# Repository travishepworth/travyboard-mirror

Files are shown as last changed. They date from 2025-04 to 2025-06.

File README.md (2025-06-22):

<h1 align="center">
travyboard
</h1>

## A corne style keyboard with the Pico SDK and TinyUSB

A personal project demonstrating how to build a keyboard using the
Raspberry Pi Pico microcontroller in c++. Intent on expanding to create more powerful
keyboards with more features (wireless coming soon).

### Photos
<div style="display: flex; justify-content: space-around;">
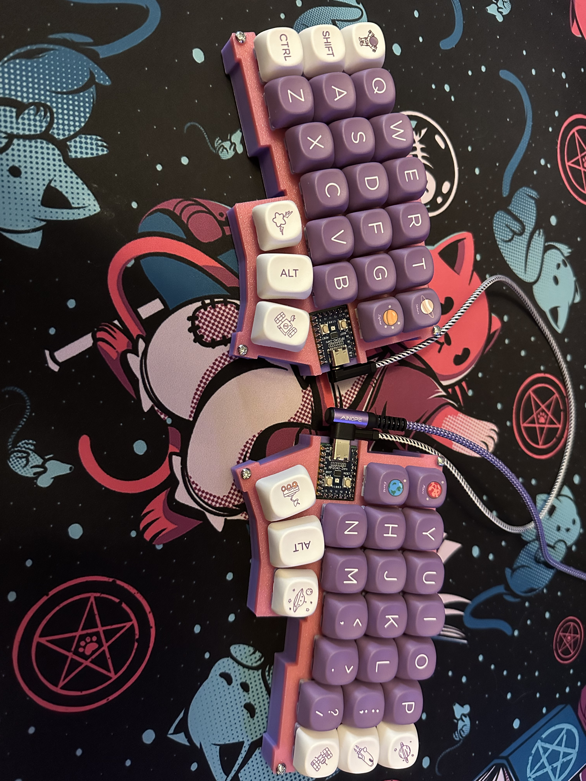
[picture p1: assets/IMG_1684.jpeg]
First Photo
  
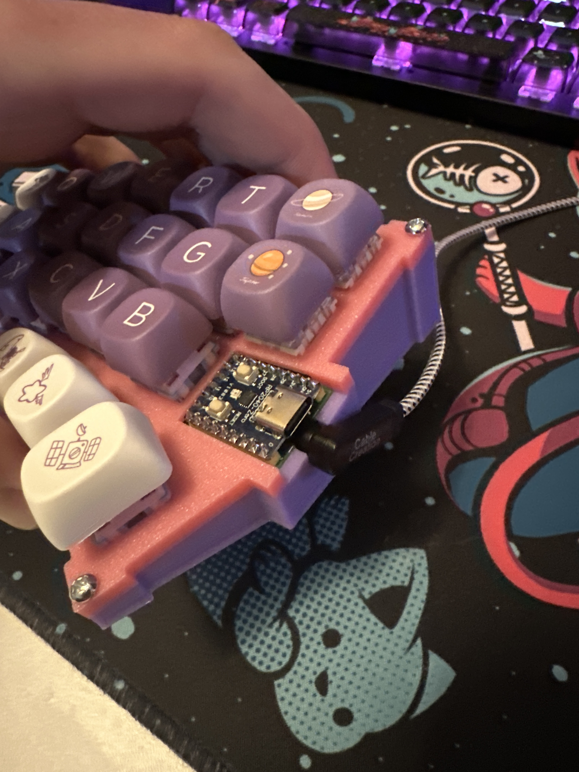
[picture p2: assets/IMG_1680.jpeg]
Second Photo
  
</div>

### Features

- 3d printed case
- 3x6 matrix with 3 button thumb clusters and 2 mode keys
- Split one way communication
- Full keymap controlled by the master pico
- Dynamic layers
- ws2812 rgb leds on every key

### Requirements for building

- Two Raspberry Pi Picos. I have the waveshare zeroes on the actual PCB.
- Cmake and gcc/g++ installed. May want to set up wsl2 on Windows.

### Setup

1. Clone this repository:

```sh
git clone https://github.com/travmonkey/travyboard.git
cd travyboard
```

2. Update the submodules:

```sh
# Includes the pico-sdk and rf modules
git submodule update --init --recursive
```

3. To build the project you need gcc-arm-none-eabi, cmake, and make installed:

```sh
cd firmware
mkdir build && cd build
cmake -DCMAKE_EXPORT_COMPILE_COMMANDS=ON ..
make
```

5. Mount and flash both picos with the master and slave compiled .uf2 code.
```sh
mkdir ~/rpi-pico
sudo fdisk -l # Find the pico device
sudo mount /dev/sdx1 /home/`<user>`/rpi-pico
sudo cp src/devices/right_half/right_half.uf2 /home/`<user>`/rpi-pico/
sudo cp src/devices/left_half/left_half.uf2 /home/`<user>`/rpi-pico/
```

Alternativly you can modify the script I wrote to include your own directories and username

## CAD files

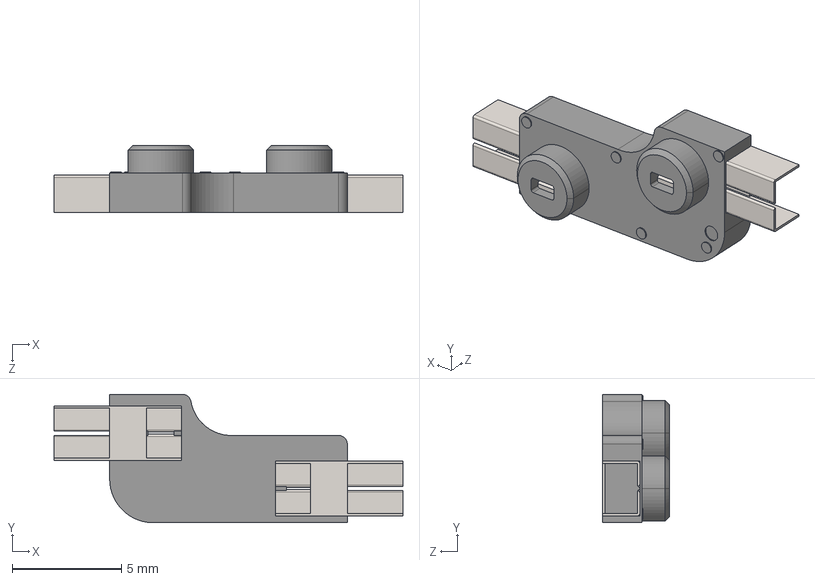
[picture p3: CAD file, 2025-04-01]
pcb/models/Kailh Hotswap MX.step
16.0 x 5.89 x 3.05 mm
Kailh Hotswap MX
Kailh Hotswap MX Inlay
Kailh Hotswap MX Inlay 2

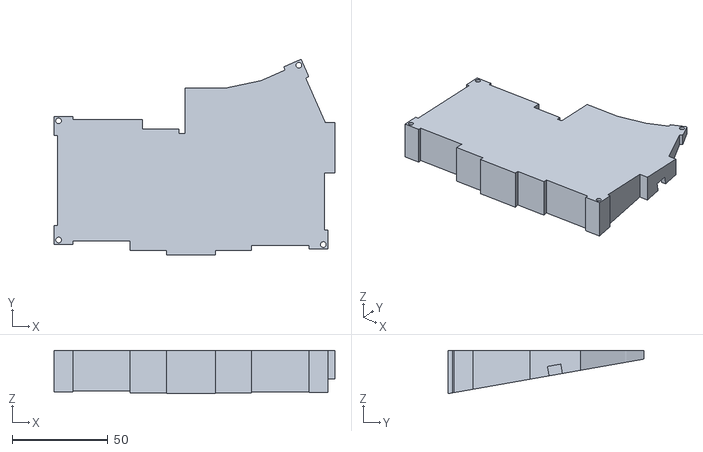
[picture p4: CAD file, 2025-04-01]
stls/Bottom.stl
147.1 x 102.4 x 22.7

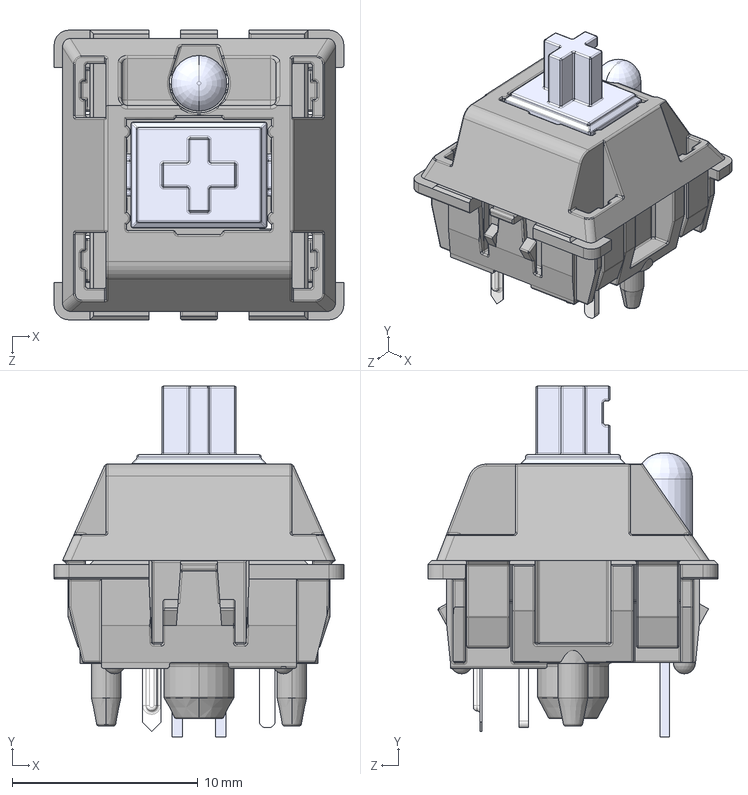
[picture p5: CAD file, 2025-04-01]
pcb/models/MX .STEP
15.6 x 18.9 x 15.6 mm
MX 轴 按键′_ü___¨1
MX 轴 轴体áì_¨￠¨__
MX粣 拸簽LEDLEDLED
MX轴 轴体 底部 μ×2__默认_á2____è_
针脚___默认__è_

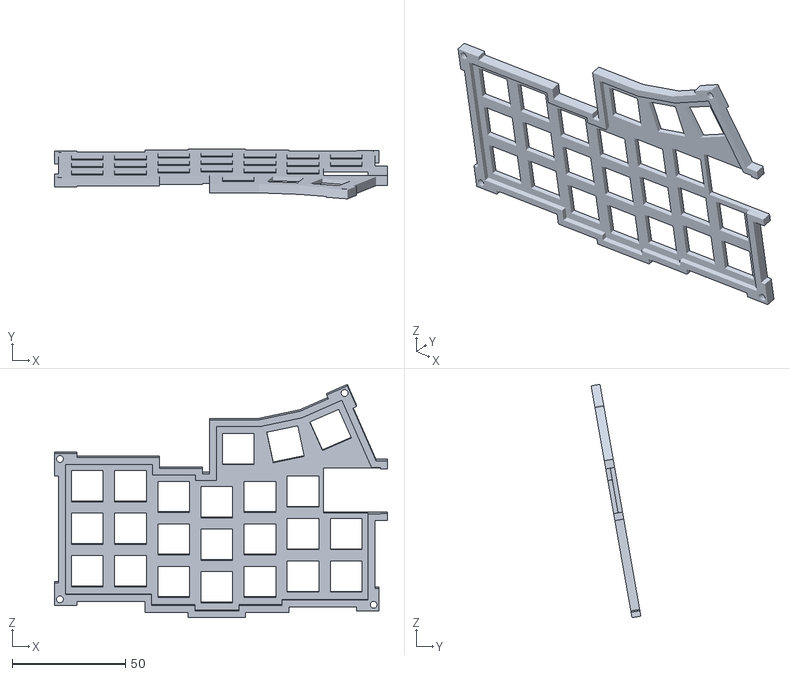
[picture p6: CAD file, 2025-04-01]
stls/Case - Top.stl
147.1 x 22.0 x 103.1

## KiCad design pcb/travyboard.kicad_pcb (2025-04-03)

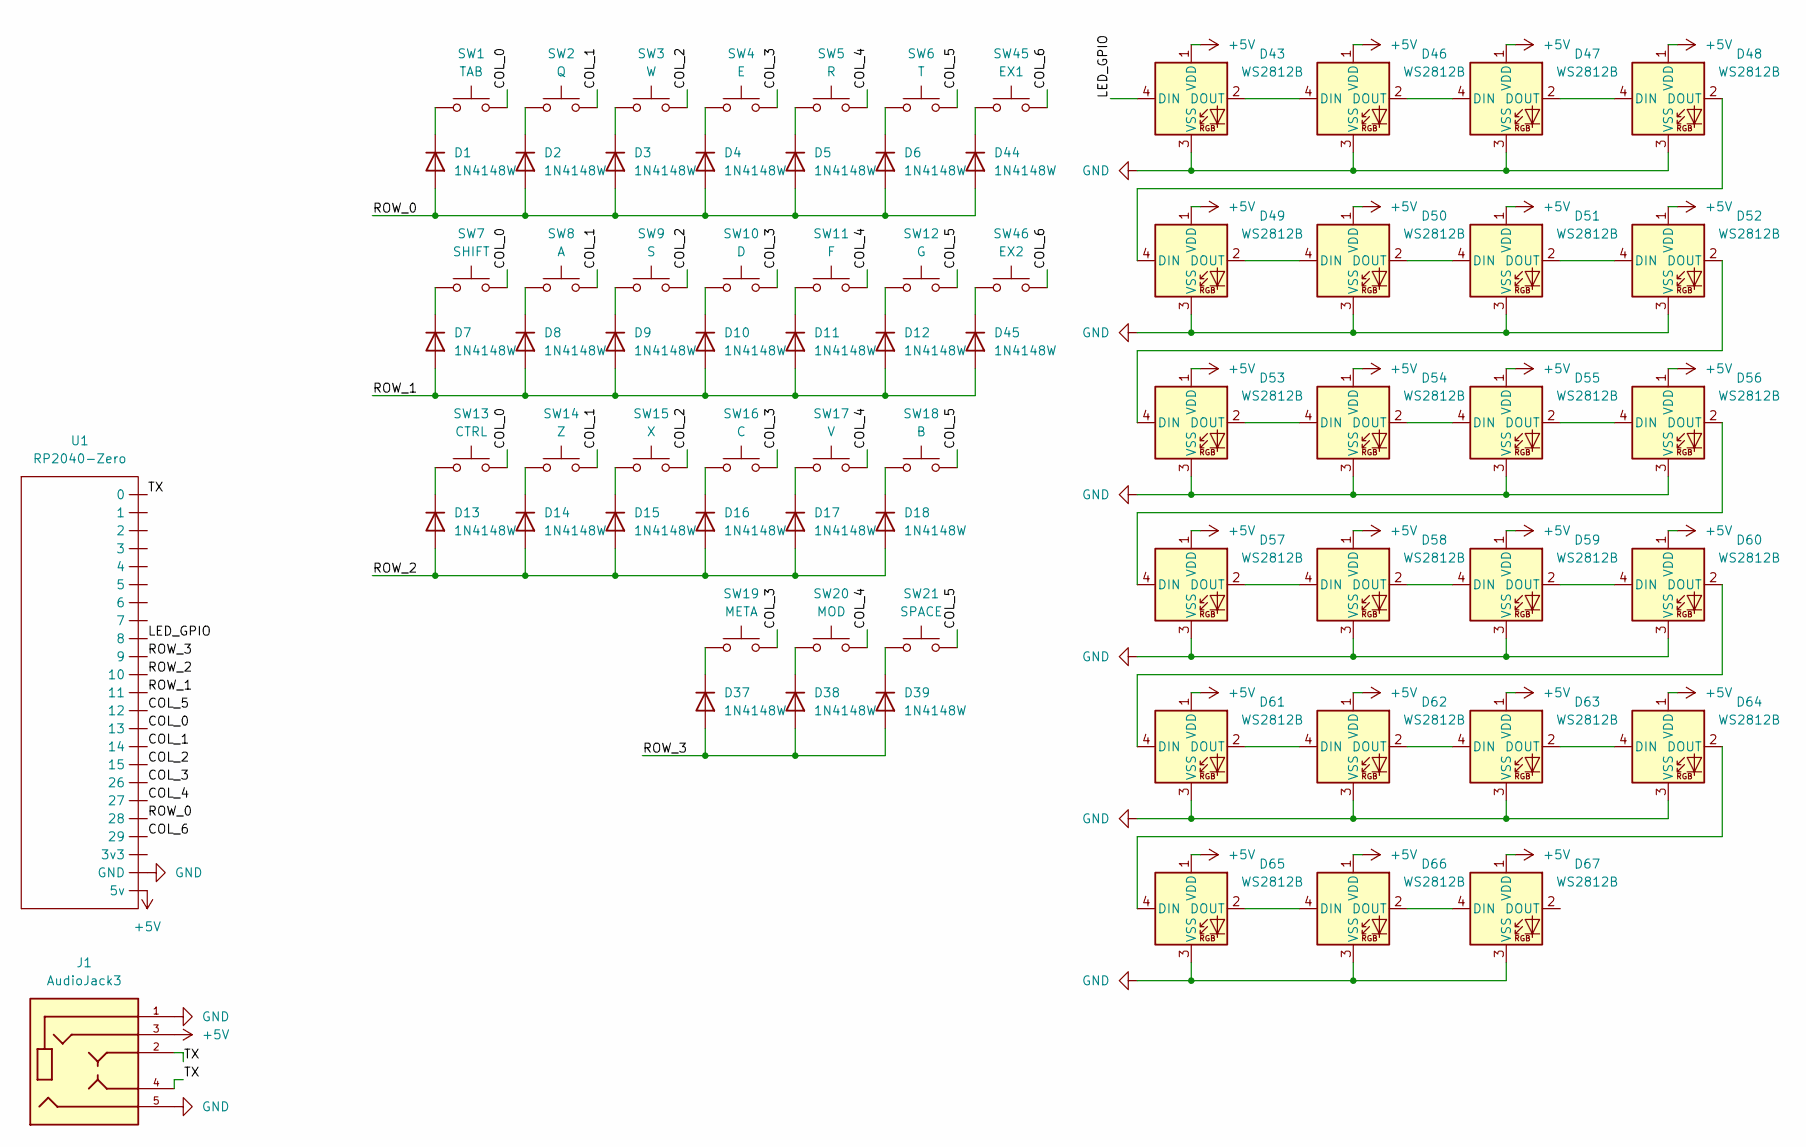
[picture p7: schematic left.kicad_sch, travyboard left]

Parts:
D1, D2, D3, D4, D5, D6, D7, D8, D9, D10, D11, D12, D13, D14, D15, D16, D17, D18, D37, D38, D39, D44, D45: 1N4148W; D_SOD-123
D43, D46, D47, D48, D49, D50, D51, D52, D53, D54, D55, D56, D57, D58, D59, D60, D61, D62, D63, D64, D65, D66, D67: WS2812B; LED_WS2812B_PLCC4_5.0x5.0mm_P3.2mm
J1: AudioJack3; CUI_SJ-3501-SMT-TR; PARTREV 1.05
SW1: TAB; CherryMX_Hotswap
SW2: Q; CherryMX_Hotswap
SW3: W; CherryMX_Hotswap
SW4: E; CherryMX_Hotswap
SW5: R; CherryMX_Hotswap
SW6: T; CherryMX_Hotswap
SW7: SHIFT; CherryMX_Hotswap
SW8: A; CherryMX_Hotswap
SW9: S; CherryMX_Hotswap
SW10: D; CherryMX_Hotswap
SW11: F; CherryMX_Hotswap
SW12: G; CherryMX_Hotswap
SW13: CTRL; CherryMX_Hotswap
SW14: Z; CherryMX_Hotswap
SW15: X; CherryMX_Hotswap
SW16: C; CherryMX_Hotswap
SW17: V; CherryMX_Hotswap
SW18: B; CherryMX_Hotswap
SW19: META; CherryMX_Hotswap
SW20: MOD; CherryMX_Hotswap
SW21: SPACE; CherryMX_Hotswap
SW45: EX1; CherryMX_Hotswap
SW46: EX2; CherryMX_Hotswap
U1: RP2040-Zero

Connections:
+5V: D43.1 (VDD), D46.1 (VDD), D47.1 (VDD), D48.1 (VDD), D49.1 (VDD), D50.1 (VDD), D51.1 (VDD), D52.1 (VDD), D53.1 (VDD), D54.1 (VDD), D55.1 (VDD), D56.1 (VDD), D57.1 (VDD), D58.1 (VDD), D59.1 (VDD), D60.1 (VDD), D61.1 (VDD), D62.1 (VDD), D63.1 (VDD), D64.1 (VDD), D65.1 (VDD), D66.1 (VDD), D67.1 (VDD), J1.3, U1.5v; also elsewhere on the board
/Left Half/COL_0: SW1.2, SW7.2, SW13.2, U1.13
/Left Half/COL_1: SW2.2, SW8.2, SW14.2, U1.14
/Left Half/COL_2: SW3.2, SW9.2, SW15.2, U1.15
/Left Half/COL_3: SW4.2, SW10.2, SW16.2, SW19.2, U1.26
/Left Half/COL_4: SW5.2, SW11.2, SW17.2, SW20.2, U1.27
/Left Half/COL_5: SW6.2, SW12.2, SW18.2, SW21.2, U1.12
/Left Half/COL_6: SW45.2, SW46.2, U1.29
/Left Half/LED_GPIO: D43.4 (DIN), U1.8
/Left Half/ROW_0: D1.2 (A), D2.2 (A), D3.2 (A), D4.2 (A), D5.2 (A), D6.2 (A), D44.2 (A), U1.28
/Left Half/ROW_1: D7.2 (A), D8.2 (A), D9.2 (A), D10.2 (A), D11.2 (A), D12.2 (A), D45.2 (A), U1.11
/Left Half/ROW_2: D13.2 (A), D14.2 (A), D15.2 (A), D16.2 (A), D17.2 (A), D18.2 (A), U1.10
/Left Half/ROW_3: D37.2 (A), D38.2 (A), D39.2 (A), U1.9
/Left Half/TX: J1.2, J1.4, U1.0
GND: D43.3 (VSS), D46.3 (VSS), D47.3 (VSS), D48.3 (VSS), D49.3 (VSS), D50.3 (VSS), D51.3 (VSS), D52.3 (VSS), D53.3 (VSS), D54.3 (VSS), D55.3 (VSS), D56.3 (VSS), D57.3 (VSS), D58.3 (VSS), D59.3 (VSS), D60.3 (VSS), D61.3 (VSS), D62.3 (VSS), D63.3 (VSS), D64.3 (VSS), D65.3 (VSS), D66.3 (VSS), D67.3 (VSS), J1.1, J1.5, U1.GND; also elsewhere on the board
unnamed: D1.1 (K), SW1.1
unnamed: D2.1 (K), SW2.1
unnamed: D3.1 (K), SW3.1
unnamed: D4.1 (K), SW4.1
unnamed: D5.1 (K), SW5.1
unnamed: D6.1 (K), SW6.1
unnamed: D7.1 (K), SW7.1
unnamed: D8.1 (K), SW8.1
unnamed: D9.1 (K), SW9.1
unnamed: D10.1 (K), SW10.1
unnamed: D11.1 (K), SW11.1
unnamed: D12.1 (K), SW12.1
unnamed: D13.1 (K), SW13.1
unnamed: D14.1 (K), SW14.1
unnamed: D15.1 (K), SW15.1
unnamed: D16.1 (K), SW16.1
unnamed: D17.1 (K), SW17.1
unnamed: D18.1 (K), SW18.1
unnamed: D37.1 (K), SW19.1
unnamed: D38.1 (K), SW20.1
unnamed: D39.1 (K), SW21.1
unnamed: D43.2 (DOUT), D46.4 (DIN)
unnamed: D44.1 (K), SW45.1
unnamed: D45.1 (K), SW46.1
unnamed: D46.2 (DOUT), D47.4 (DIN)
unnamed: D47.2 (DOUT), D48.4 (DIN)
unnamed: D48.2 (DOUT), D49.4 (DIN)
unnamed: D49.2 (DOUT), D50.4 (DIN)
unnamed: D50.2 (DOUT), D51.4 (DIN)
unnamed: D51.2 (DOUT), D52.4 (DIN)
unnamed: D52.2 (DOUT), D53.4 (DIN)
unnamed: D53.2 (DOUT), D54.4 (DIN)
unnamed: D54.2 (DOUT), D55.4 (DIN)
unnamed: D55.2 (DOUT), D56.4 (DIN)
unnamed: D56.2 (DOUT), D57.4 (DIN)
unnamed: D57.2 (DOUT), D58.4 (DIN)
unnamed: D58.2 (DOUT), D59.4 (DIN)
unnamed: D59.2 (DOUT), D60.4 (DIN)
unnamed: D60.2 (DOUT), D61.4 (DIN)
unnamed: D61.2 (DOUT), D62.4 (DIN)
unnamed: D62.2 (DOUT), D63.4 (DIN)
unnamed: D63.2 (DOUT), D64.4 (DIN)
unnamed: D64.2 (DOUT), D65.4 (DIN)
unnamed: D65.2 (DOUT), D66.4 (DIN)
unnamed: D66.2 (DOUT), D67.4 (DIN)

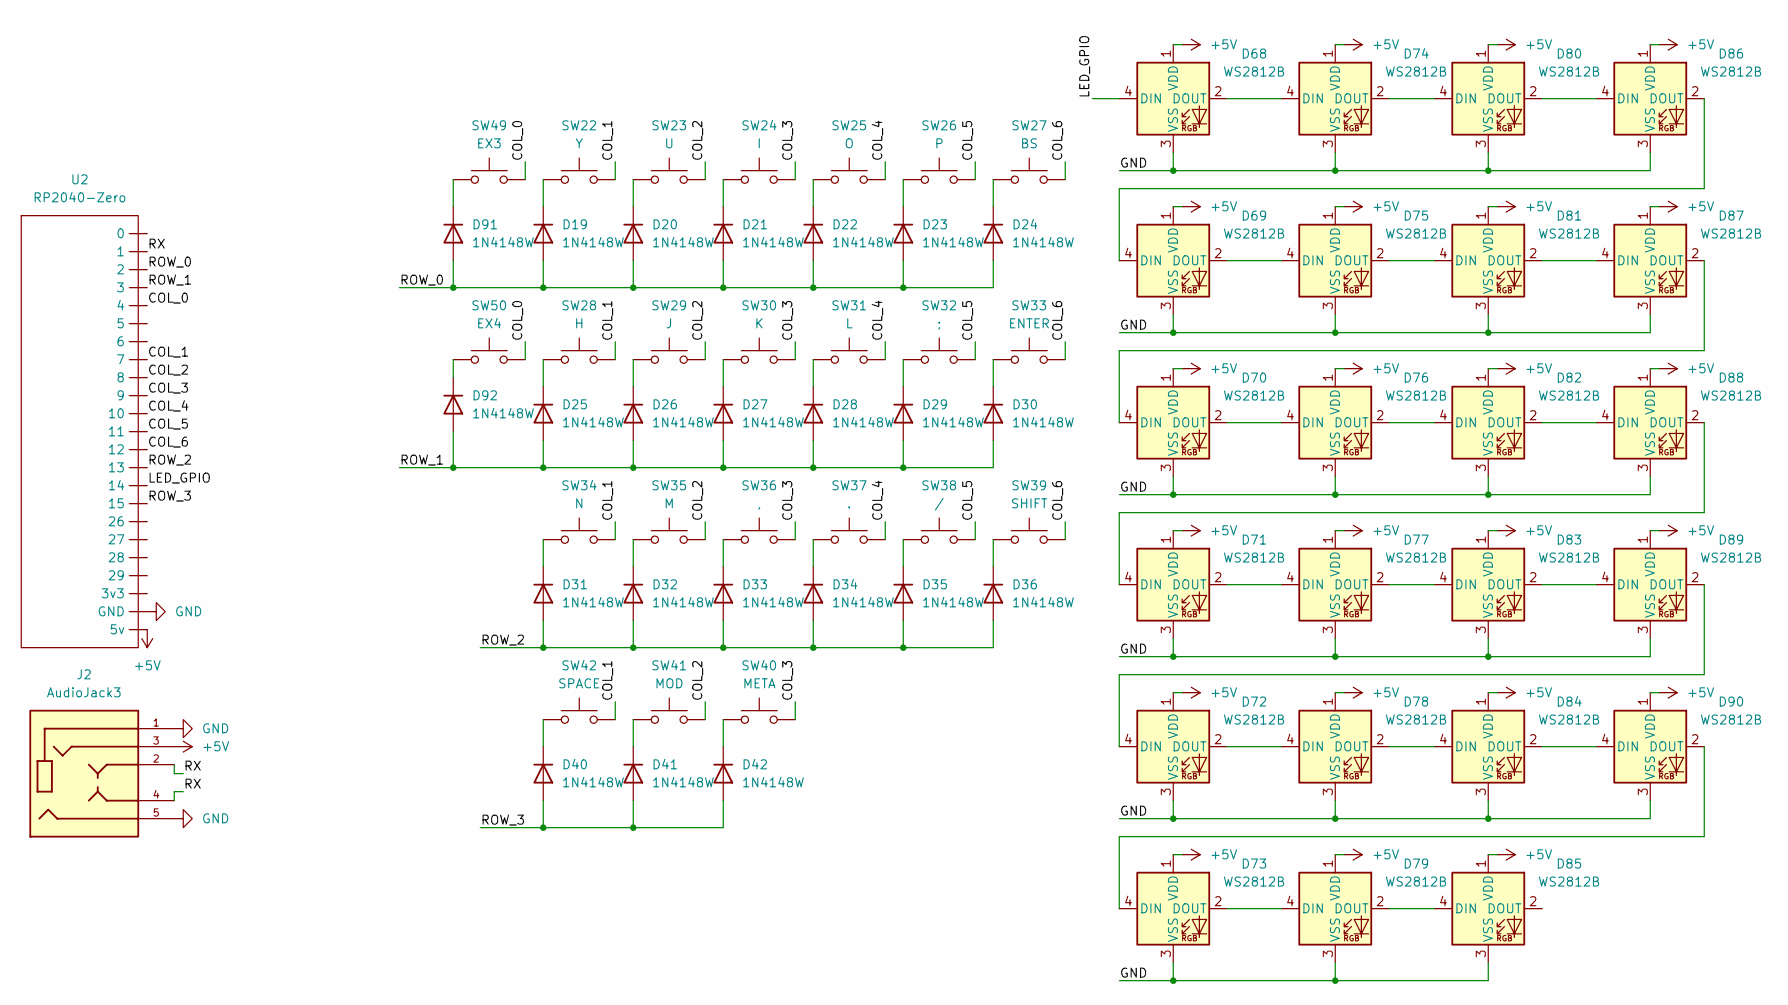
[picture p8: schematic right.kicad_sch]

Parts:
D19, D20, D21, D22, D23, D24, D25, D26, D27, D28, D29, D30, D31, D32, D33, D34, D35, D36, D40, D41, D42, D91, D92: 1N4148W; D_SOD-123
D68, D69, D70, D71, D72, D73, D74, D75, D76, D77, D78, D79, D80, D81, D82, D83, D84, D85, D86, D87, D88, D89, D90: WS2812B; LED_WS2812B_PLCC4_5.0x5.0mm_P3.2mm
J2: AudioJack3; CUI_SJ-3501-SMT-TR; PARTREV 1.05
SW22: Y; CherryMX_Hotswap
SW23: U; CherryMX_Hotswap
SW24: I; CherryMX_Hotswap
SW25: O; CherryMX_Hotswap
SW26: P; CherryMX_Hotswap
SW27: BS; CherryMX_Hotswap
SW28: H; CherryMX_Hotswap
SW29: J; CherryMX_Hotswap
SW30: K; CherryMX_Hotswap
SW31: L; CherryMX_Hotswap
SW32: ;; CherryMX_Hotswap
SW33: ENTER; CherryMX_Hotswap
SW34: N; CherryMX_Hotswap
SW35: M; CherryMX_Hotswap
SW36: ,; CherryMX_Hotswap
SW37: .; CherryMX_Hotswap
SW38: /; CherryMX_Hotswap
SW39: SHIFT; CherryMX_Hotswap
SW40: META; CherryMX_Hotswap
SW41: MOD; CherryMX_Hotswap
SW42: SPACE; CherryMX_Hotswap
SW49: EX3; CherryMX_Hotswap
SW50: EX4; CherryMX_Hotswap
U2: RP2040-Zero

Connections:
+5V: D68.1 (VDD), D69.1 (VDD), D70.1 (VDD), D71.1 (VDD), D72.1 (VDD), D73.1 (VDD), D74.1 (VDD), D75.1 (VDD), D76.1 (VDD), D77.1 (VDD), D78.1 (VDD), D79.1 (VDD), D80.1 (VDD), D81.1 (VDD), D82.1 (VDD), D83.1 (VDD), D84.1 (VDD), D85.1 (VDD), D86.1 (VDD), D87.1 (VDD), D88.1 (VDD), D89.1 (VDD), D90.1 (VDD), J2.3, U2.5v; also elsewhere on the board
/Right Half/COL_0: SW49.2, SW50.2, U2.4
/Right Half/COL_1: SW22.2, SW28.2, SW34.2, SW42.2, U2.7
/Right Half/COL_2: SW23.2, SW29.2, SW35.2, SW41.2, U2.8
/Right Half/COL_3: SW24.2, SW30.2, SW36.2, SW40.2, U2.9
/Right Half/COL_4: SW25.2, SW31.2, SW37.2, U2.10
/Right Half/COL_5: SW26.2, SW32.2, SW38.2, U2.11
/Right Half/COL_6: SW27.2, SW33.2, SW39.2, U2.12
/Right Half/LED_GPIO: D68.4 (DIN), U2.14
/Right Half/ROW_0: D19.2 (A), D20.2 (A), D21.2 (A), D22.2 (A), D23.2 (A), D24.2 (A), D91.2 (A), U2.2
/Right Half/ROW_1: D25.2 (A), D26.2 (A), D27.2 (A), D28.2 (A), D29.2 (A), D30.2 (A), D92.2 (A), U2.3
/Right Half/ROW_2: D31.2 (A), D32.2 (A), D33.2 (A), D34.2 (A), D35.2 (A), D36.2 (A), U2.13
/Right Half/ROW_3: D40.2 (A), D41.2 (A), D42.2 (A), U2.15
/Right Half/RX: J2.2, J2.4, U2.1
GND: D68.3 (VSS), D69.3 (VSS), D70.3 (VSS), D71.3 (VSS), D72.3 (VSS), D73.3 (VSS), D74.3 (VSS), D75.3 (VSS), D76.3 (VSS), D77.3 (VSS), D78.3 (VSS), D79.3 (VSS), D80.3 (VSS), D81.3 (VSS), D82.3 (VSS), D83.3 (VSS), D84.3 (VSS), D85.3 (VSS), D86.3 (VSS), D87.3 (VSS), D88.3 (VSS), D89.3 (VSS), D90.3 (VSS), J2.1, J2.5, U2.GND; also elsewhere on the board
unnamed: D19.1 (K), SW22.1
unnamed: D20.1 (K), SW23.1
unnamed: D21.1 (K), SW24.1
unnamed: D22.1 (K), SW25.1
unnamed: D23.1 (K), SW26.1
unnamed: D24.1 (K), SW27.1
unnamed: D25.1 (K), SW28.1
unnamed: D26.1 (K), SW29.1
unnamed: D27.1 (K), SW30.1
unnamed: D28.1 (K), SW31.1
unnamed: D29.1 (K), SW32.1
unnamed: D30.1 (K), SW33.1
unnamed: D31.1 (K), SW34.1
unnamed: D32.1 (K), SW35.1
unnamed: D33.1 (K), SW36.1
unnamed: D34.1 (K), SW37.1
unnamed: D35.1 (K), SW38.1
unnamed: D36.1 (K), SW39.1
unnamed: D40.1 (K), SW42.1
unnamed: D41.1 (K), SW41.1
unnamed: D42.1 (K), SW40.1
unnamed: D68.2 (DOUT), D74.4 (DIN)
unnamed: D69.4 (DIN), D86.2 (DOUT)
unnamed: D69.2 (DOUT), D75.4 (DIN)
unnamed: D70.4 (DIN), D87.2 (DOUT)
unnamed: D70.2 (DOUT), D76.4 (DIN)
unnamed: D71.4 (DIN), D88.2 (DOUT)
unnamed: D71.2 (DOUT), D77.4 (DIN)
unnamed: D72.4 (DIN), D89.2 (DOUT)
unnamed: D72.2 (DOUT), D78.4 (DIN)
unnamed: D73.4 (DIN), D90.2 (DOUT)
unnamed: D73.2 (DOUT), D79.4 (DIN)
unnamed: D74.2 (DOUT), D80.4 (DIN)
unnamed: D75.2 (DOUT), D81.4 (DIN)
unnamed: D76.2 (DOUT), D82.4 (DIN)
unnamed: D77.2 (DOUT), D83.4 (DIN)
unnamed: D78.2 (DOUT), D84.4 (DIN)
unnamed: D79.2 (DOUT), D85.4 (DIN)
unnamed: D80.2 (DOUT), D86.4 (DIN)
unnamed: D81.2 (DOUT), D87.4 (DIN)
unnamed: D82.2 (DOUT), D88.4 (DIN)
unnamed: D83.2 (DOUT), D89.4 (DIN)
unnamed: D84.2 (DOUT), D90.4 (DIN)
unnamed: D91.1 (K), SW49.1
unnamed: D92.1 (K), SW50.1

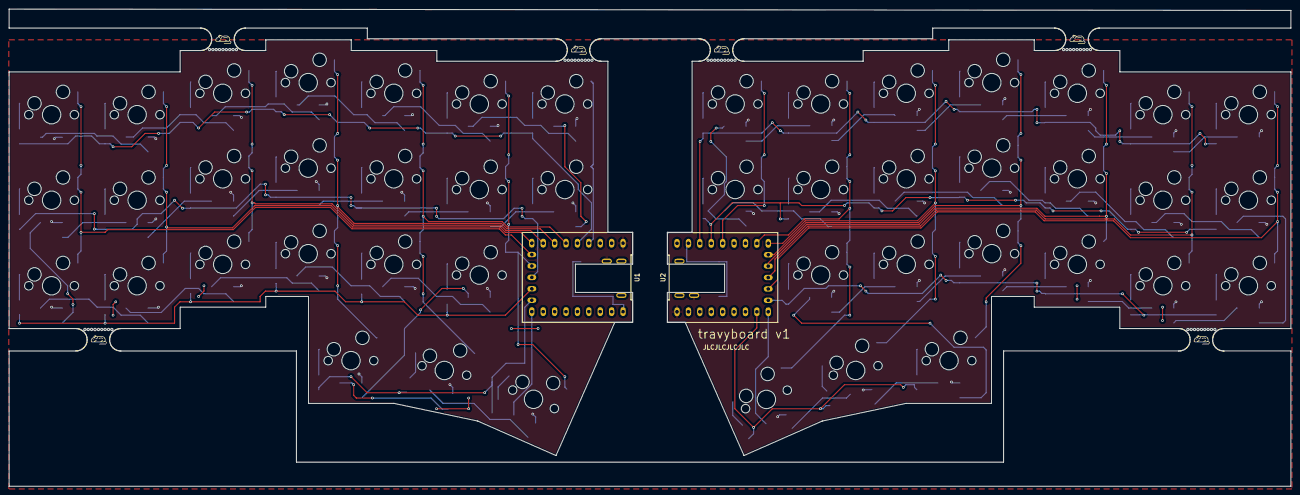
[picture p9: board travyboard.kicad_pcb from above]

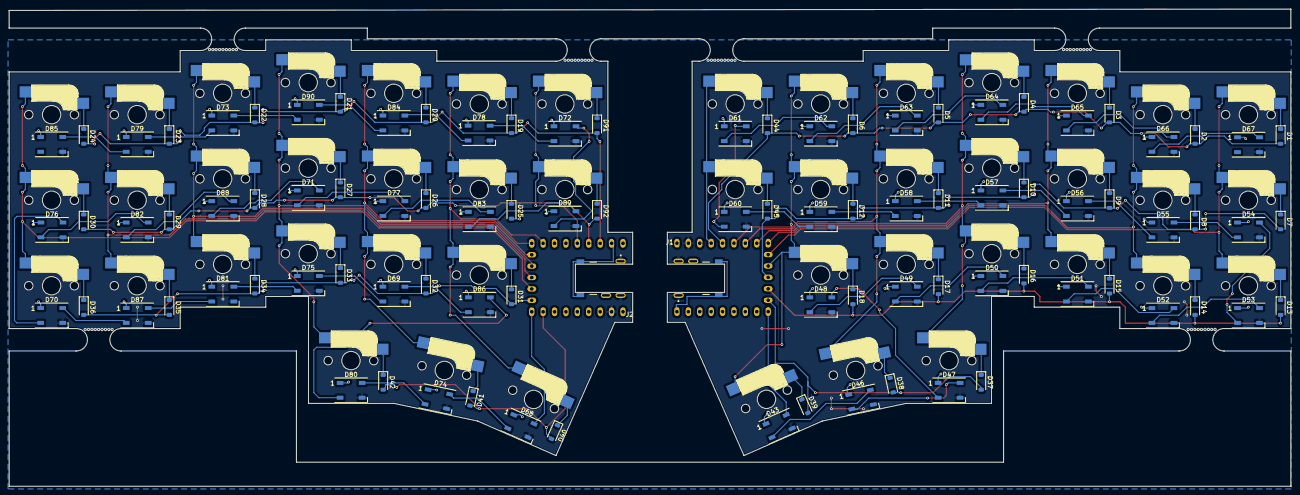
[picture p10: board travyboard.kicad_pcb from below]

Board: 2 copper layers, 285.5 x 106.3 mm, 148 parts (94 on the bottom side), 118 nets.

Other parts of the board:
mouse-bite-5mm-10mm, mouse-bite-5mm-10mm#2, mouse-bite-5mm-10mm#3, mouse-bite-5mm-10mm#4, mouse-bite-5mm-10mm#5, mouse-bite-5mm-10mm#6: VAL**; mouse-bite-5mm-10mm

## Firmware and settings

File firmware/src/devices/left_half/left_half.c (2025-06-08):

/*--Main--*/
#include "bsp/board_api.h"
#include <hardware/uart.h>

#include "debounce.h"

#include "matrix.h"
#include "uart.h"

static matrix_metadata_t metadata;
static uart_report_t uart_report;
static debounce_state_t debounce_state;
static matrix_state_t previous_state;

int main(void) {
  board_init();
  initialize_uart();

  select_matrix_backend();
  matrix_init(&metadata);
  initialize_uart_report(&uart_report);
  debounce_init(&debounce_state);
  matrix_clear(&previous_state);

  static uint32_t last_send_ms = 0;
  const uint32_t heartbeat_interval_ms = 5;
  const uint32_t interval_ms = 1;
  static uint32_t start_ms = 0;

  while (true) {
    uint32_t current_ms = board_millis();

    // Always scan matrix at consistent intervals
    if (current_ms - start_ms >= interval_ms) {
      start_ms = current_ms; // Reset to current time (prevents drift)

      matrix_state_t state;
      matrix_clear(&state);
      matrix_read(&state, &metadata);
      debounce_matrix(&state, &debounce_state);

      bool state_changed = !matrix_state_equals(&state, &previous_state);
      bool heartbeat_due = (current_ms - last_send_ms) >= heartbeat_interval_ms;

      if (state_changed || heartbeat_due) {
        pack_uart_report(&state, &uart_report);

        // Try to send, but update state regardless
        if (send_uart_report(&uart_report)) {
          last_send_ms = current_ms;
        }
        // Always update previous_state to prevent spam retries
        matrix_copy(&previous_state, state);
      }
    }

    // Optional: small sleep to prevent busy waiting
    sleep_us(100);
  }
  return 0;
};

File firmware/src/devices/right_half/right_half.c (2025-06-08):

/*--Main--*/
#include "bsp/board_api.h"
#include <hardware/uart.h>

#include "debounce.h"
#include "tusb.h"

#include "keyboard.h"
#include "keymap.h"
#include "matrix.h"
#include "uart.h"

static keymap_t keymap;
static keycode_report_t report;
static matrix_metadata_t metadata;
static debounce_state_t debounce_state;
static matrix_state_t left_state;
static uart_report_t uart_report;

int main(void) {
  board_init();
  tusb_init();

  initialize_uart();
  initialize_uart_report(&uart_report);

  keyboard_init(&keymap, &metadata);
  debounce_init(&debounce_state);
  matrix_clear(&left_state);

  const uint32_t interval_ms = 1;
  static uint32_t start_ms = 0;

  while (true) {
    tud_task();
    uint32_t current_ms = board_millis();
    if (current_ms - start_ms >= interval_ms) {
      start_ms = current_ms;

      matrix_state_t true_state;
      matrix_state_t right_state;
      matrix_clear(&true_state);
      matrix_clear(&right_state);

      // TODO: move to function, a bit too much logic for main
      if (uart_is_readable(UART_ID)) {
        clear_uart_report(&uart_report);
        matrix_state_t incoming_state;
        matrix_clear(&incoming_state);

        if (receive_uart_report(&incoming_state, &uart_report)) {
          matrix_copy(&left_state, incoming_state);
        }
      }
      matrix_copy(&true_state, left_state);

      matrix_read(&right_state, &metadata);
      debounce_matrix(&right_state, &debounce_state);
      // TODO: make this take 3 arguments, instead of copying right to true
      matrix_concatenate(&true_state, &right_state);

      matrix_convert(&true_state); // Extract array of indices from scan

      set_layer(&keymap, get_active_layer(true_state, &keymap.layer_indices));

      set_keycodes(&keymap, &report, &true_state);
      send_keyboard_report(&report);
    }
  }
  return 0;
};

// TODO: move to tusb.c

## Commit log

2025-03-17 Rework edgecuts and change to waveshare rp2040 zero
    [left.kicad_sch, right.kicad_sch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]
2025-04-01 Finalize pcb for printing
    [Kailh Hotswap MX.step, MX .STEP, left.kicad_sch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]
2025-04-01 Implement smarter layer switching
2025-04-01 Add stls for the keyboard case
    [Bottom.stl, Case - Top.stl]
2025-04-03 Remove kicad backups from git
    [travyboard.kicad_pcb, travyboard.kicad_sch]
2025-05-23 Optimize board reading
2025-05-30 Init uart files
2025-06-07 More structured uart packet
2025-06-07 Optimize flow
2025-06-08 Fix UART recieve and transmit
    [uart.c]
